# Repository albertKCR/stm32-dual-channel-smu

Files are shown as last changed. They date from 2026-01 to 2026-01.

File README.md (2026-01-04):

# Low-Cost Dual-Channel SMU

An open-source dual-channel Source Measure Unit (SMU) prototype designed for electrical and electrochemical measurements, developed as a Bachelor's thesis in Electronic Engineering.

The system integrates precision analog hardware, embedded firmware, and graphical user interfaces to provide functionality comparable to commercial SMUs at a significantly lower cost.

## Project Overview

This SMU features two fully independent channels, each capable of operating as a potentiostat or galvanostat, supporting common voltammetric and galvanostatic techniques.  
System control is handled by an STM32 microcontroller, with both embedded (DWIN display) and PC-based (C# / WPF) user interfaces.

> **Project status:** Prototype / Research
> 
> **Project total cost:** USD 410.

---

## Repository Structure

This repository is organized as follows:

```text
.
├── DWIN_display_interface     # Embedded graphical interface (DWIN DGUS project)
├── PCB_Gerber                 # PCB fabrication files used for manufacturing and BOM
├── STM32_firmware             # Embedded firmware running on the STM32 microcontroller
├── Schematics                 # Complete electrical schematics of the SMU
├── Windows_interface          # PC-based user interface (C# / WPF)
├── figures                    # Images used in the README and documentation
├── LICENSE                    # Project license
├── bachelor_thesis_pt-br.pdf  # Bachelor's thesis describing the SMU design and validation (pt-br only)
└── README.md

```

---

## System Architecture

### Functional Block Diagram

<!-- INSERT IMAGE: Overall SMU block diagram -->
<!-- Suggested: block diagram showing Power Supply, Voltage Source, Current Source, Ammeter, Voltmeter, MCU, Interfaces -->
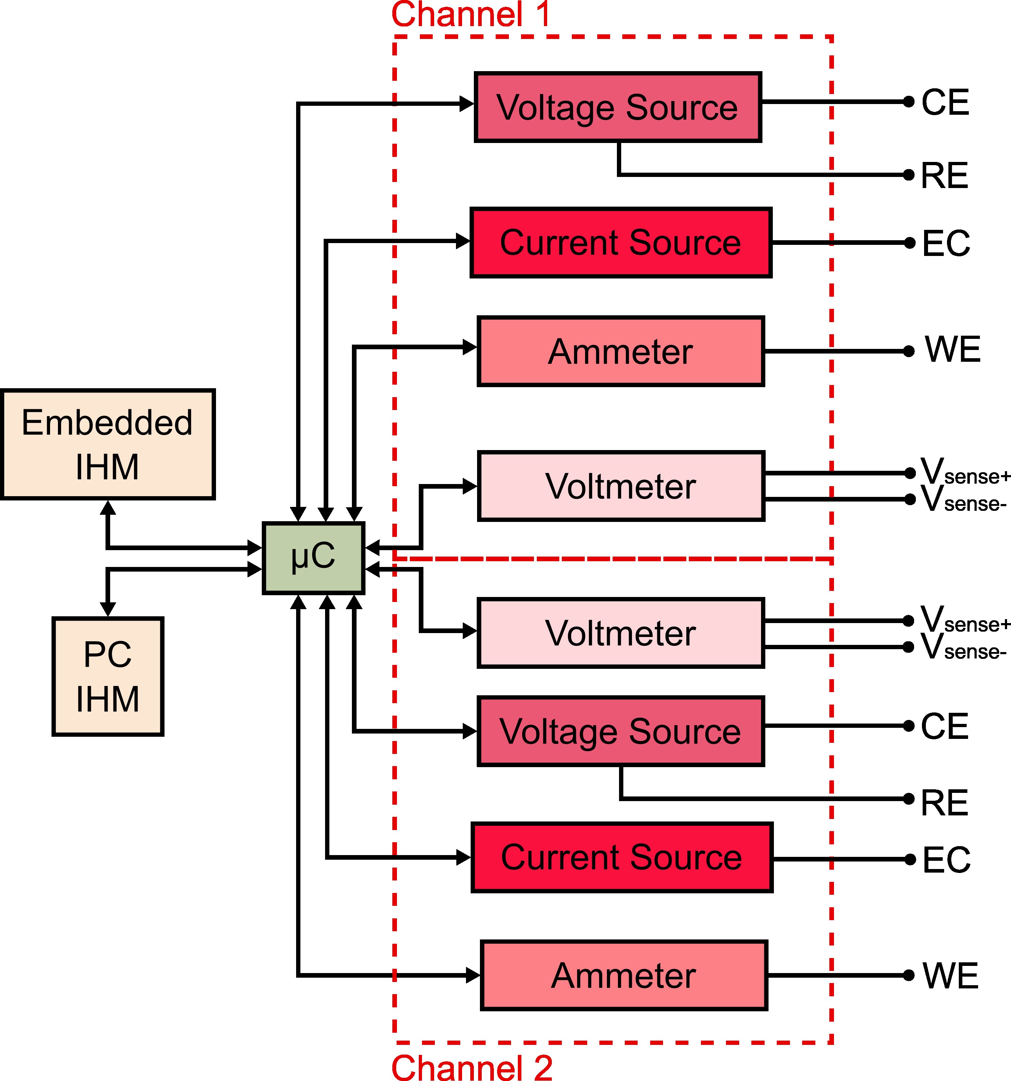
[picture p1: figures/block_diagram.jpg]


The hardware architecture is divided into five main stages per channel:
- Power supply
- Voltage source
- Current source
- Ammeter
- Voltmeter

### Electrodes

### Potentiostat Mode

In potentiostatic operation, the SMU uses a three-electrode configuration:

- Working Electrode (WE): terminal where the electrochemical reaction occurs. The SMU controls its potential relative to the Reference Electrode and measures the resulting current.
- Counter Electrode (CE): provides the current path required to maintain the controlled potential at the Working Electrode.
- Reference Electrode (RE): used exclusively for voltage sensing, providing a stable reference potential without conducting significant current.

For non-electrochemical measurements, the Counter and Reference electrodes may be connected together, allowing the potentiostat to operate as a voltage buffer.

### Galvanostat Mode

In galvanostatic operation, the SMU applies a controlled current and measures the resulting voltage:

- Current Electrode (EC): injects the defined current into the device or electrochemical cell.
- Voltage Sense (+ / −): measure the voltage response independently of the current path, enabling accurate voltage measurements across the device under test.

---

## Hardware Overview

### Key Components

- **DAC8760** – Precision 16-bit DAC for voltage and current generation  
- **ADS1262** – 32-bit ADC for high-resolution voltage and current measurements  
- **ADG1408** – Analog multiplexer for automatic transimpedance gain selection  
- **STM32F401CCU6** – Central controller and communication hub  
- **DWIN DMG80480C070_04WTC** – Embedded HMI display

### Measurement Capabilities

- Output voltage: **−10 V to +10 V**
- Output current: **−10 mA to +10 mA**
- Voltage resolution: ~**500 µV**
- Current resolution: ~**500 pA**
- Automatic current range switching

### PCB

<!-- INSERT IMAGE: PCB top and bottom views -->
<!-- Suggested: rendered PCB + real board photo -->

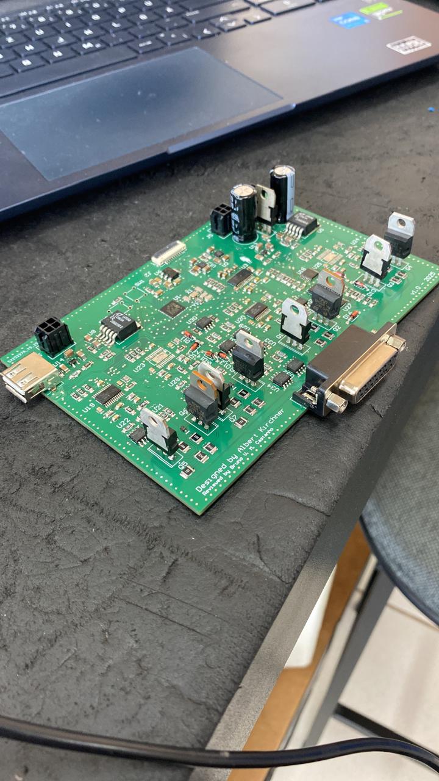
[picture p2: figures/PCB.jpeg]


The PCB integrates all analog, digital, and power stages, including dedicated connectors for electrodes, power input, USB communication, and the DWIN display.

---

## Firmware Architecture

The firmware is written in C using STM32 HAL and organized into modular libraries:

- **DAC8760** – SPI communication and output control
- **ADS1262** – ADC configuration and data acquisition
- **DWIN** – UART-based display communication
- **SMU** – High-level control, measurement logic, and technique execution

The SMU library acts as the core abstraction layer, managing:
- Channel configuration
- Source and measure operations
- Electrochemical techniques
- Communication with both interfaces

---

## Supported Techniques

### Potentiostatic
- Linear Sweep Voltammetry (LSV)
- Cyclic Voltammetry (CV)
- Differential Pulse Voltammetry (DPV)
- Square Wave Voltammetry (SWV)

### Galvanostatic
- Chronopotentiometry (CP)
- Linear Sweep Potentiometry (LSP)
- Cyclic Potentiometry (CyP)

Both **single-channel** and **synchronous dual-channel** measurements are supported.

---

## User Interfaces

### PC Interface (C# / WPF)

<!-- INSERT IMAGE: PC interface screenshot -->
<!-- Suggested: main window showing real-time plots -->
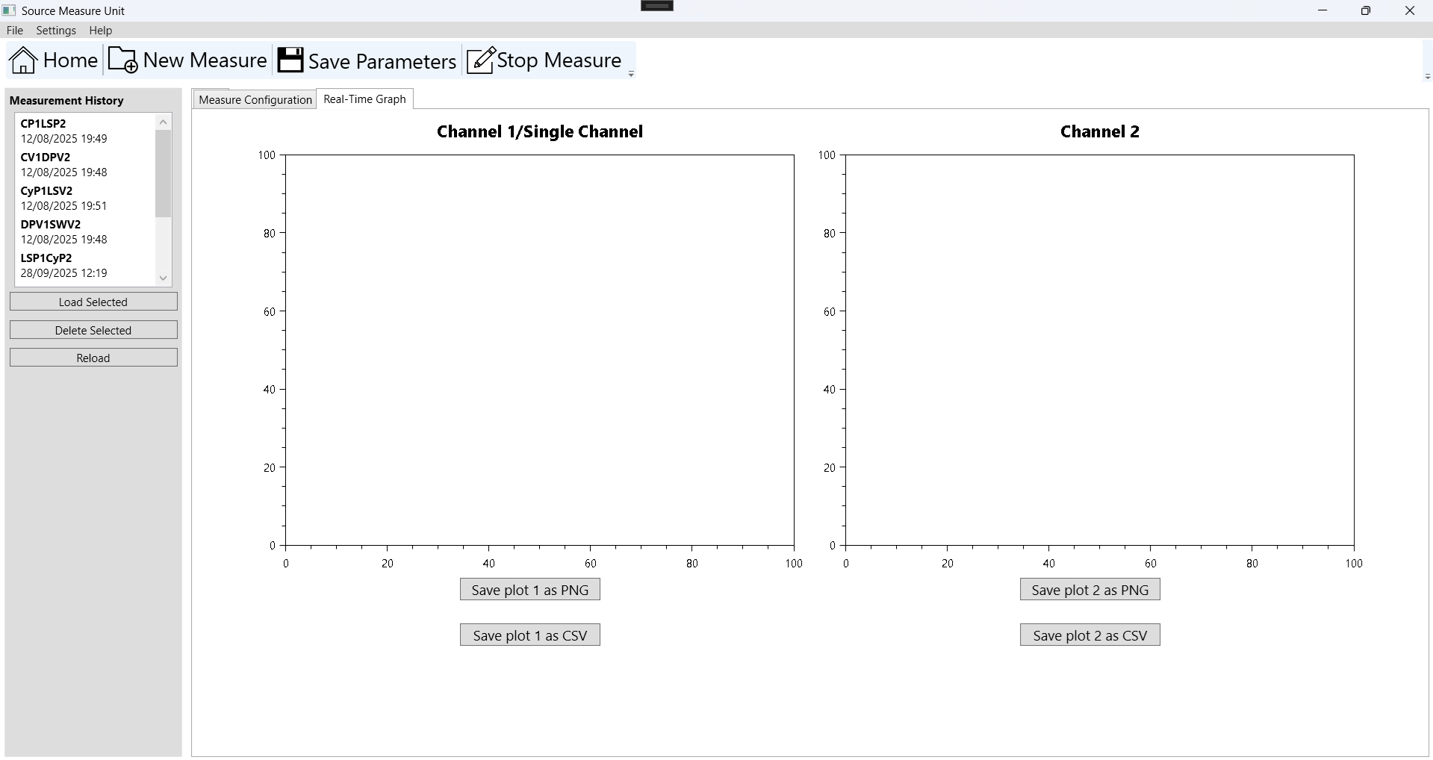
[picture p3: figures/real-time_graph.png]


The PC interface provides:
- Full configuration of measurement parameters
- Real-time plotting
- Dual-channel visualization
- Data export to CSV and PNG
- Measurement history management

Communication is performed via USB-CDC.

### Embedded Interface (DWIN)

<!-- INSERT IMAGE: DWIN display screens -->
<!-- Suggested: menu page + parameter configuration page -->
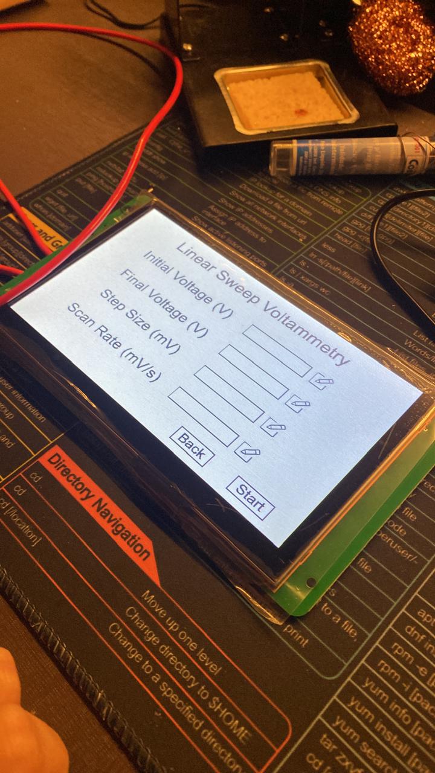
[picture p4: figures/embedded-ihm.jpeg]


The embedded interface enables:
- Standalone operation
- Technique selection
- Parameter configuration
- Numeric display of applied and measured values

---

## Future Work

- Automatic ADS1262 PGA gain selection
- Improved averaging and filtering strategies
- PCB layout refinements
- Higher power output stages

---

## Author

Developed by Albert Kirchner

Bachelor Thesis – Electronics Engineering

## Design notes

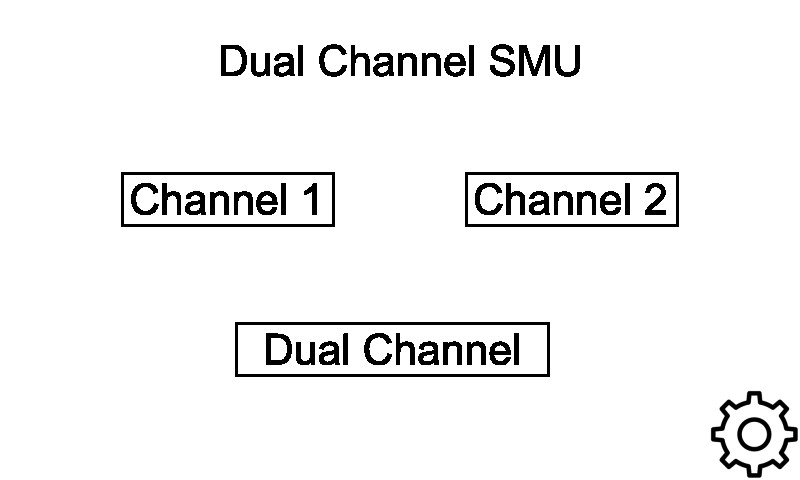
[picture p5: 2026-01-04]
DWIN_display_interface/DWIN_SET/00_dwin_firstPage.jpg

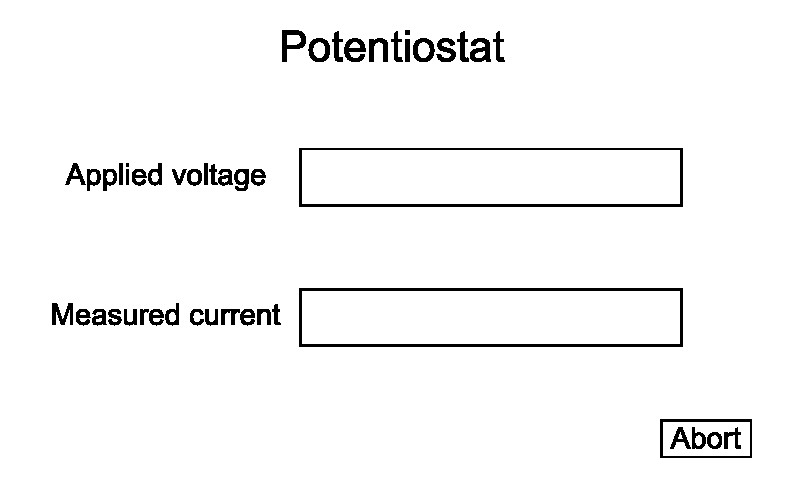
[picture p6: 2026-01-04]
DWIN_display_interface/DWIN_SET/11_dwin_potentiostatReasult.jpg

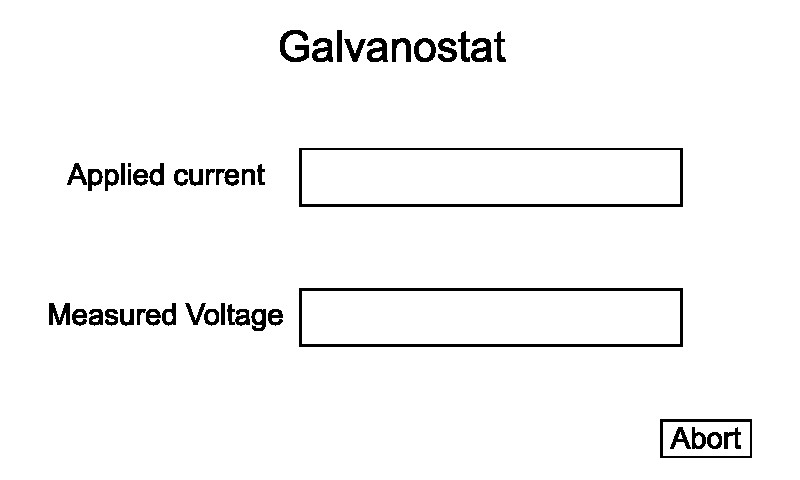
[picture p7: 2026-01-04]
DWIN_display_interface/DWIN_SET/10_dwin_galvanostatReasult.jpg

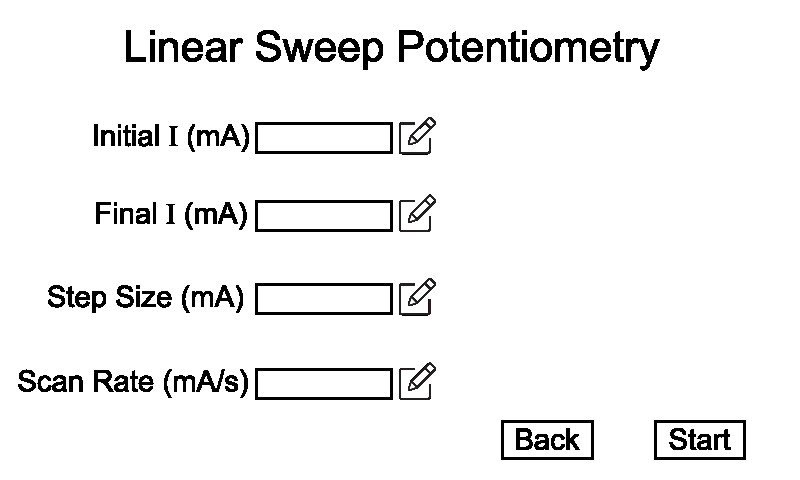
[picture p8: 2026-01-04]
DWIN_display_interface/DWIN_SET/07_dwin_LSP.jpg

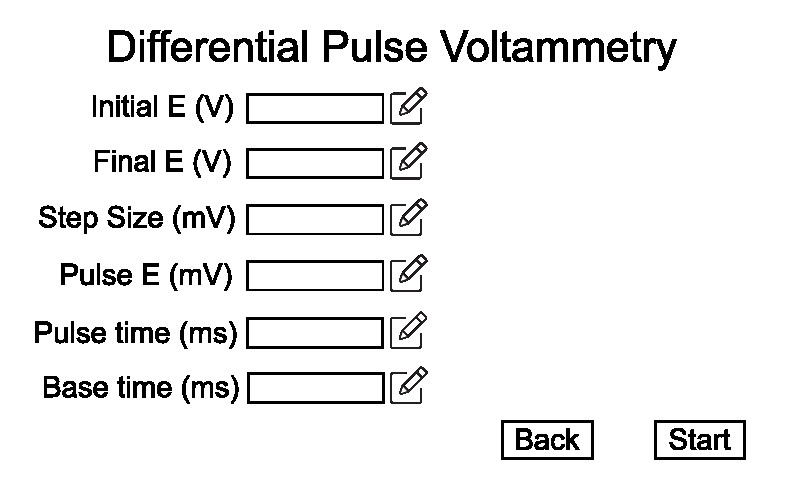
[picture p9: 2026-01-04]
DWIN_display_interface/DWIN_SET/04_dwin_DPV.jpg

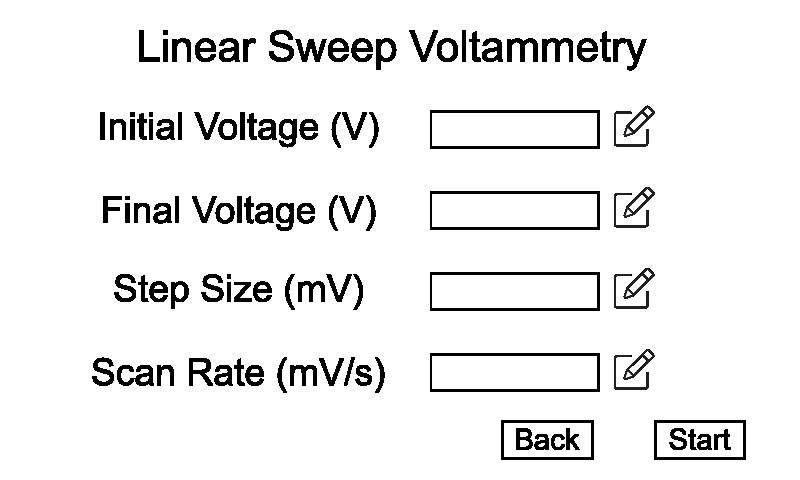
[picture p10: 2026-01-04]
DWIN_display_interface/DWIN_SET/02_dwin_LSV.jpg

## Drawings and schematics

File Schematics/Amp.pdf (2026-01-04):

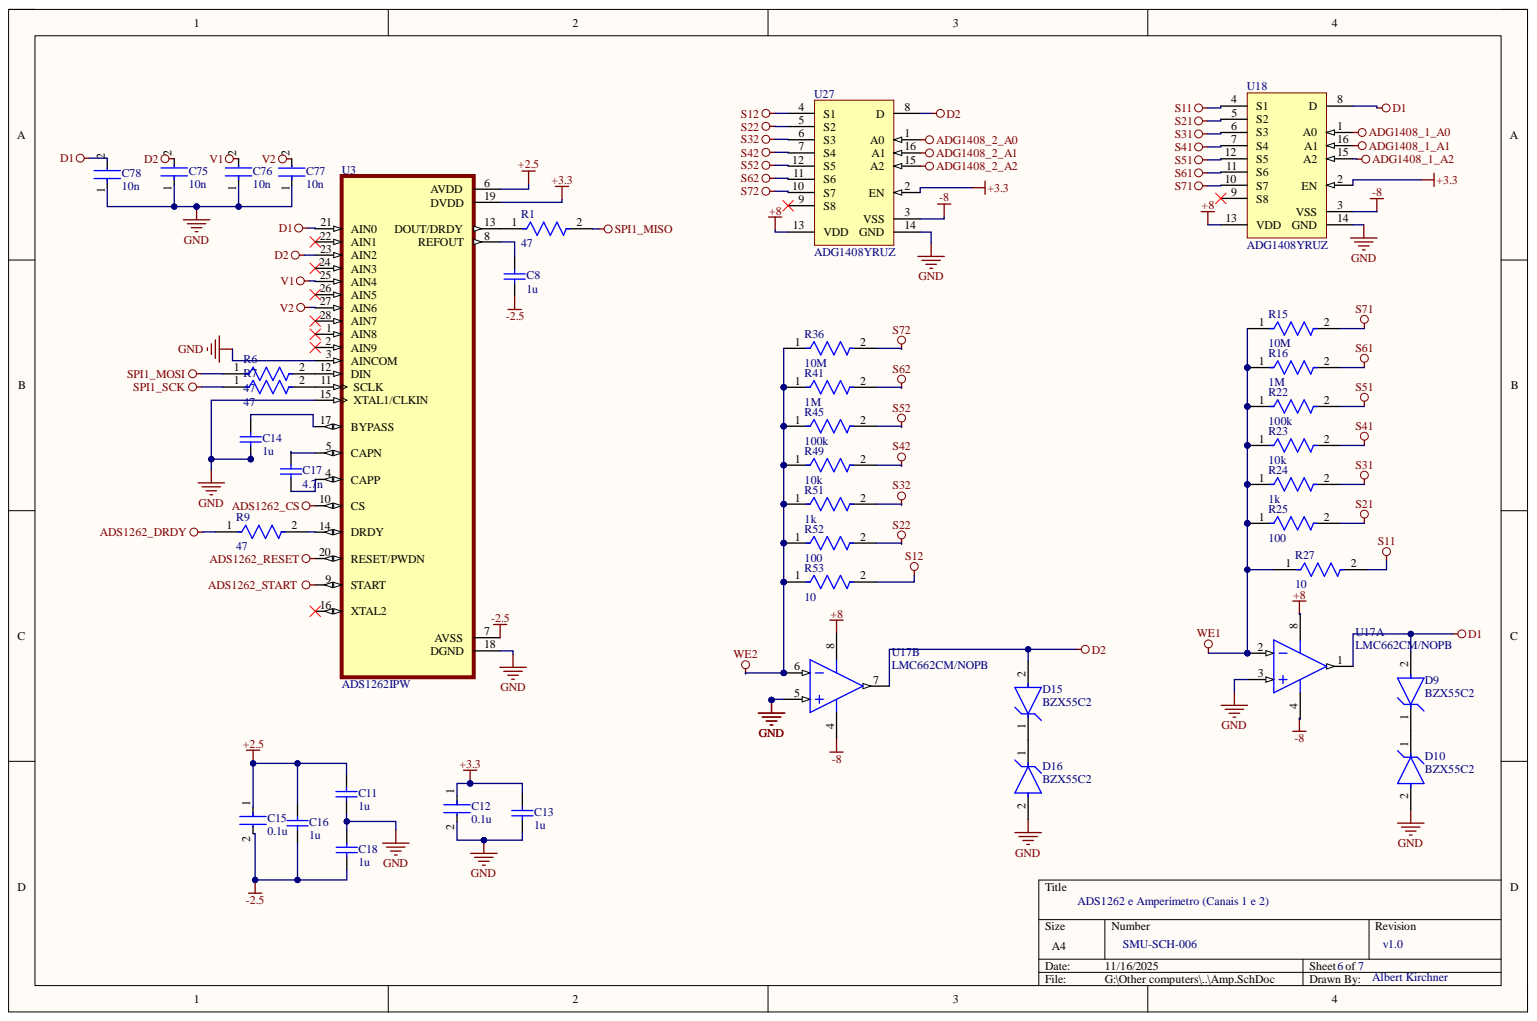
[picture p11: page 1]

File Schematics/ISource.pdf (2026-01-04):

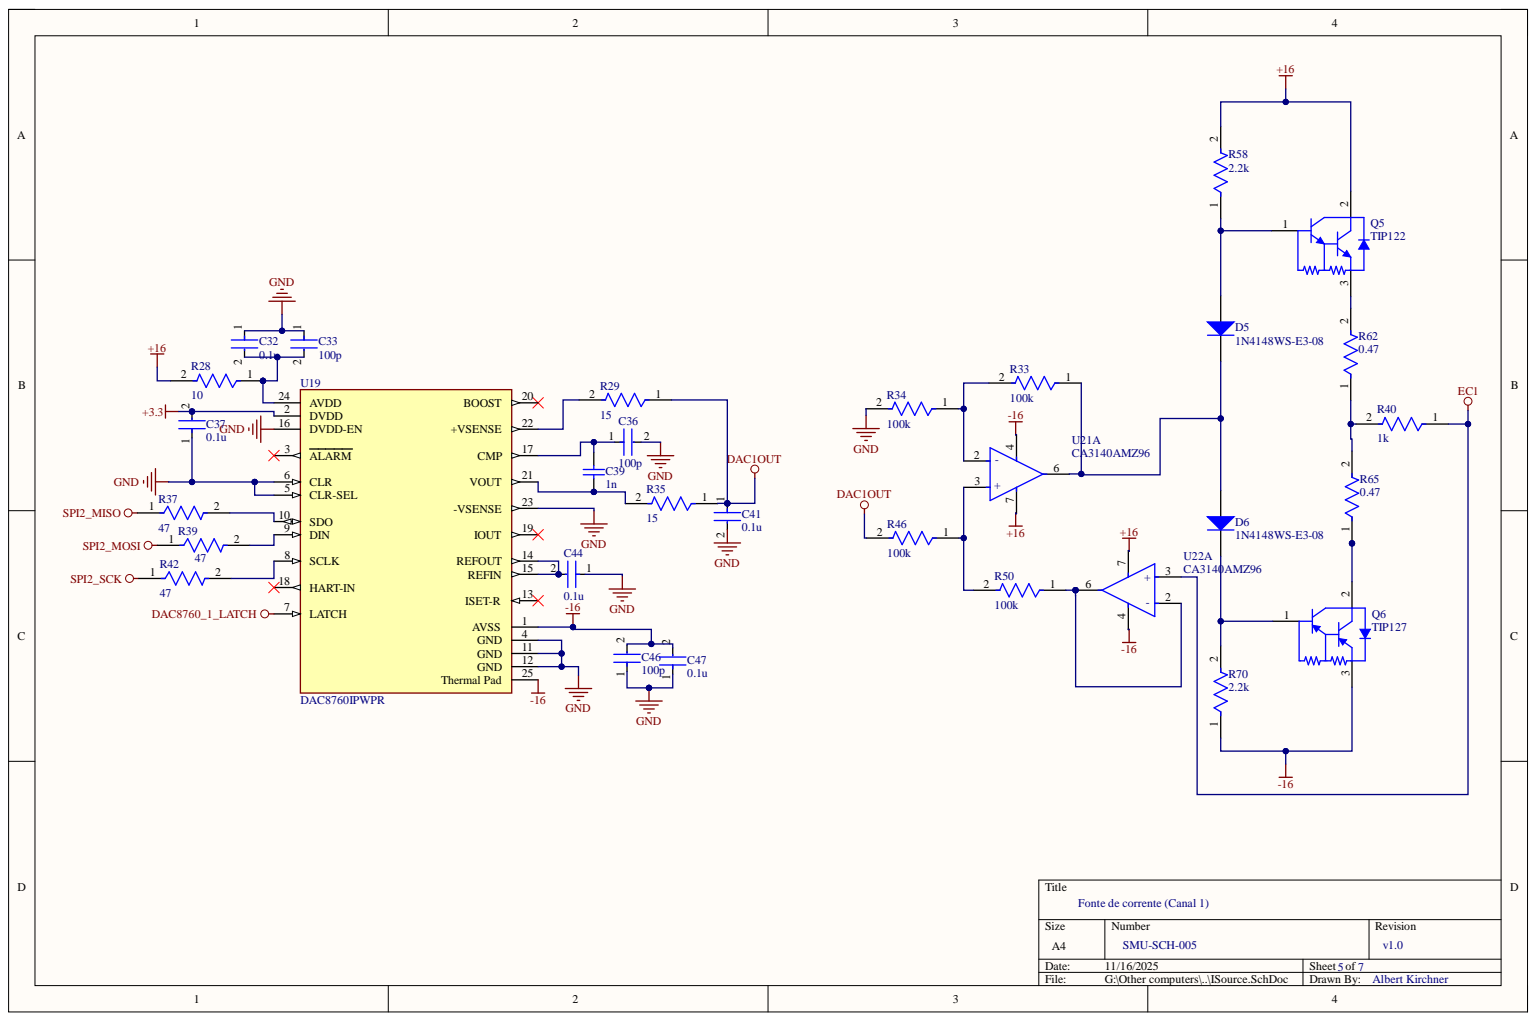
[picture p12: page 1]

1 1
1 2
2 5

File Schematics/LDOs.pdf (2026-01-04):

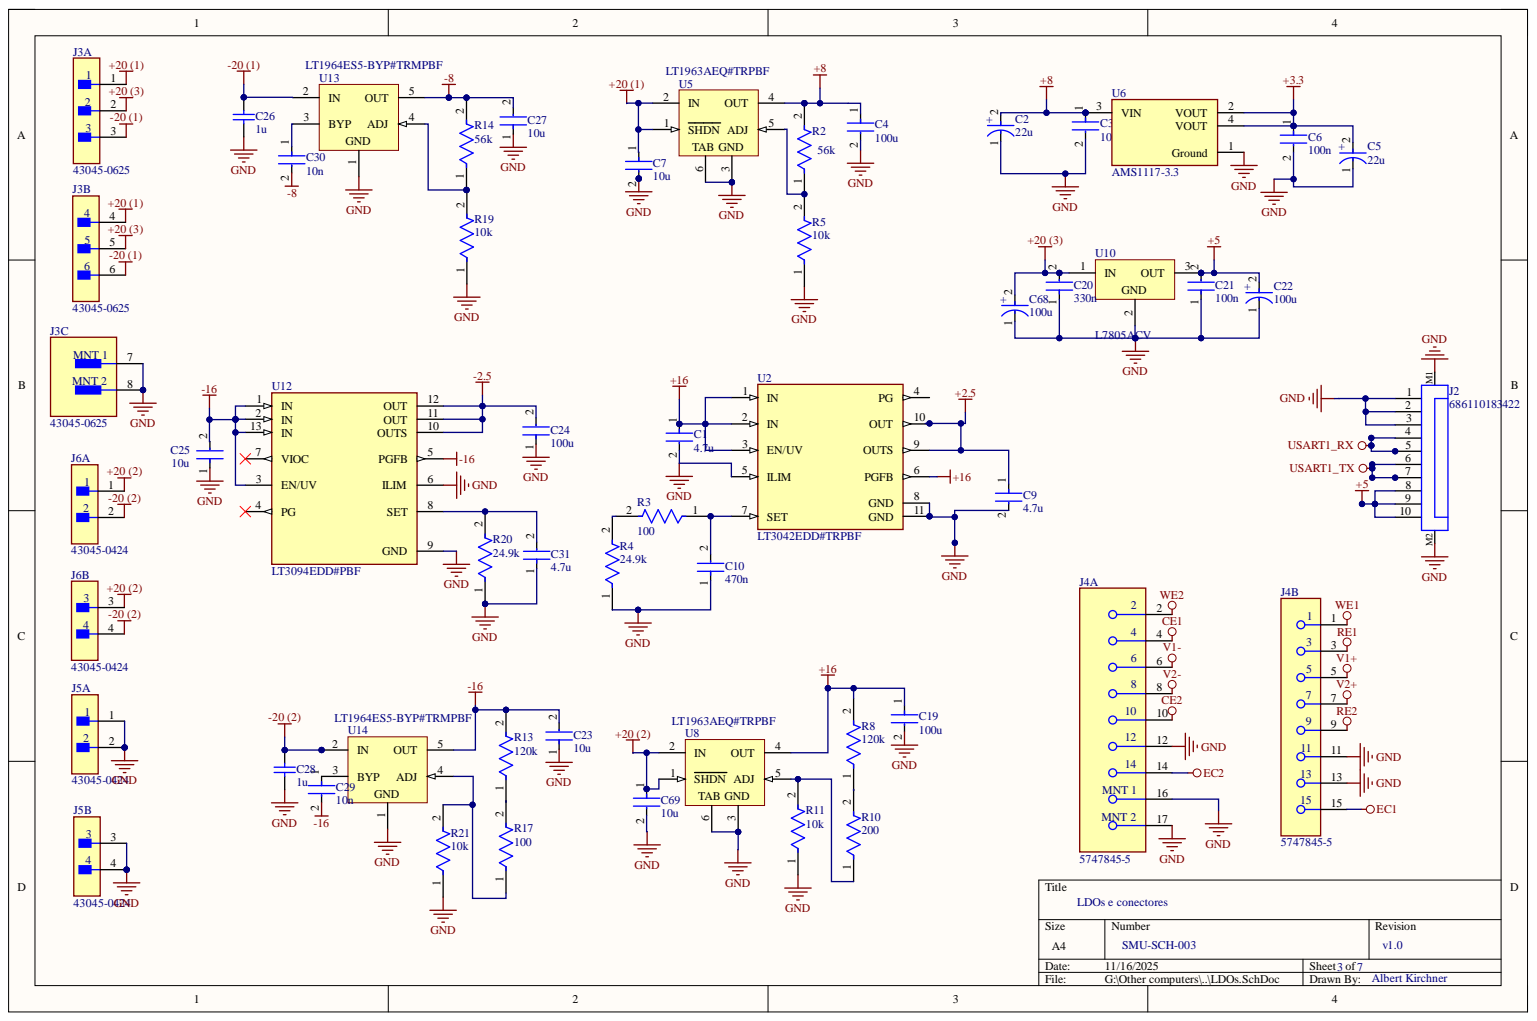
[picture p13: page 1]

2 | | 1 1
1 3 | | 1 0

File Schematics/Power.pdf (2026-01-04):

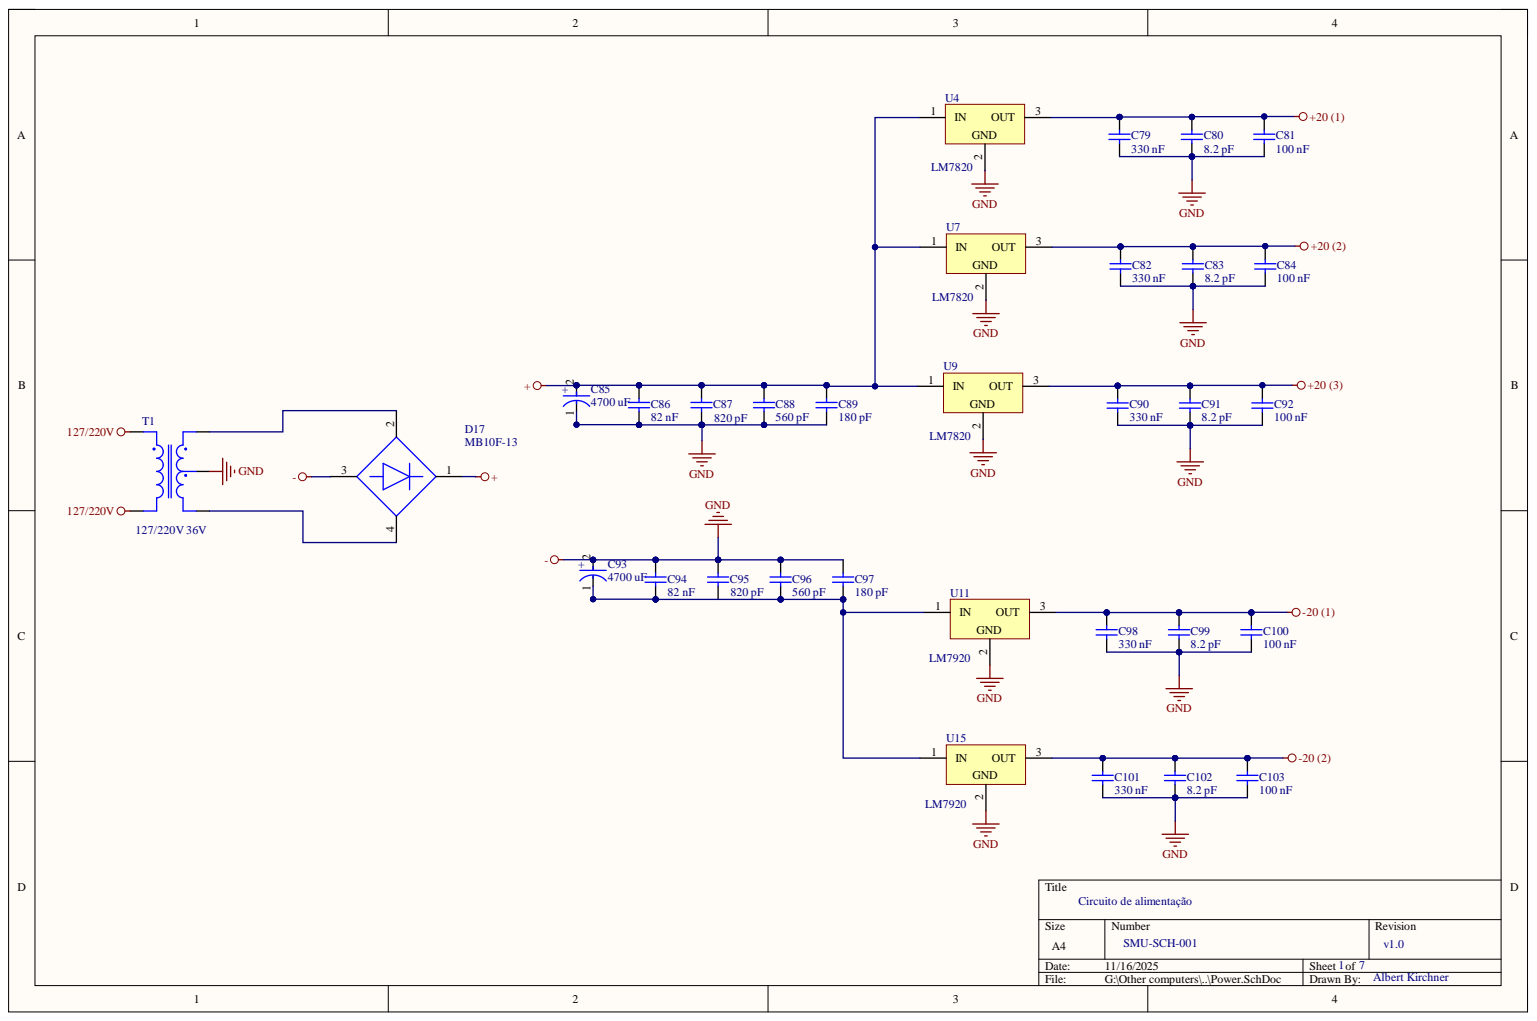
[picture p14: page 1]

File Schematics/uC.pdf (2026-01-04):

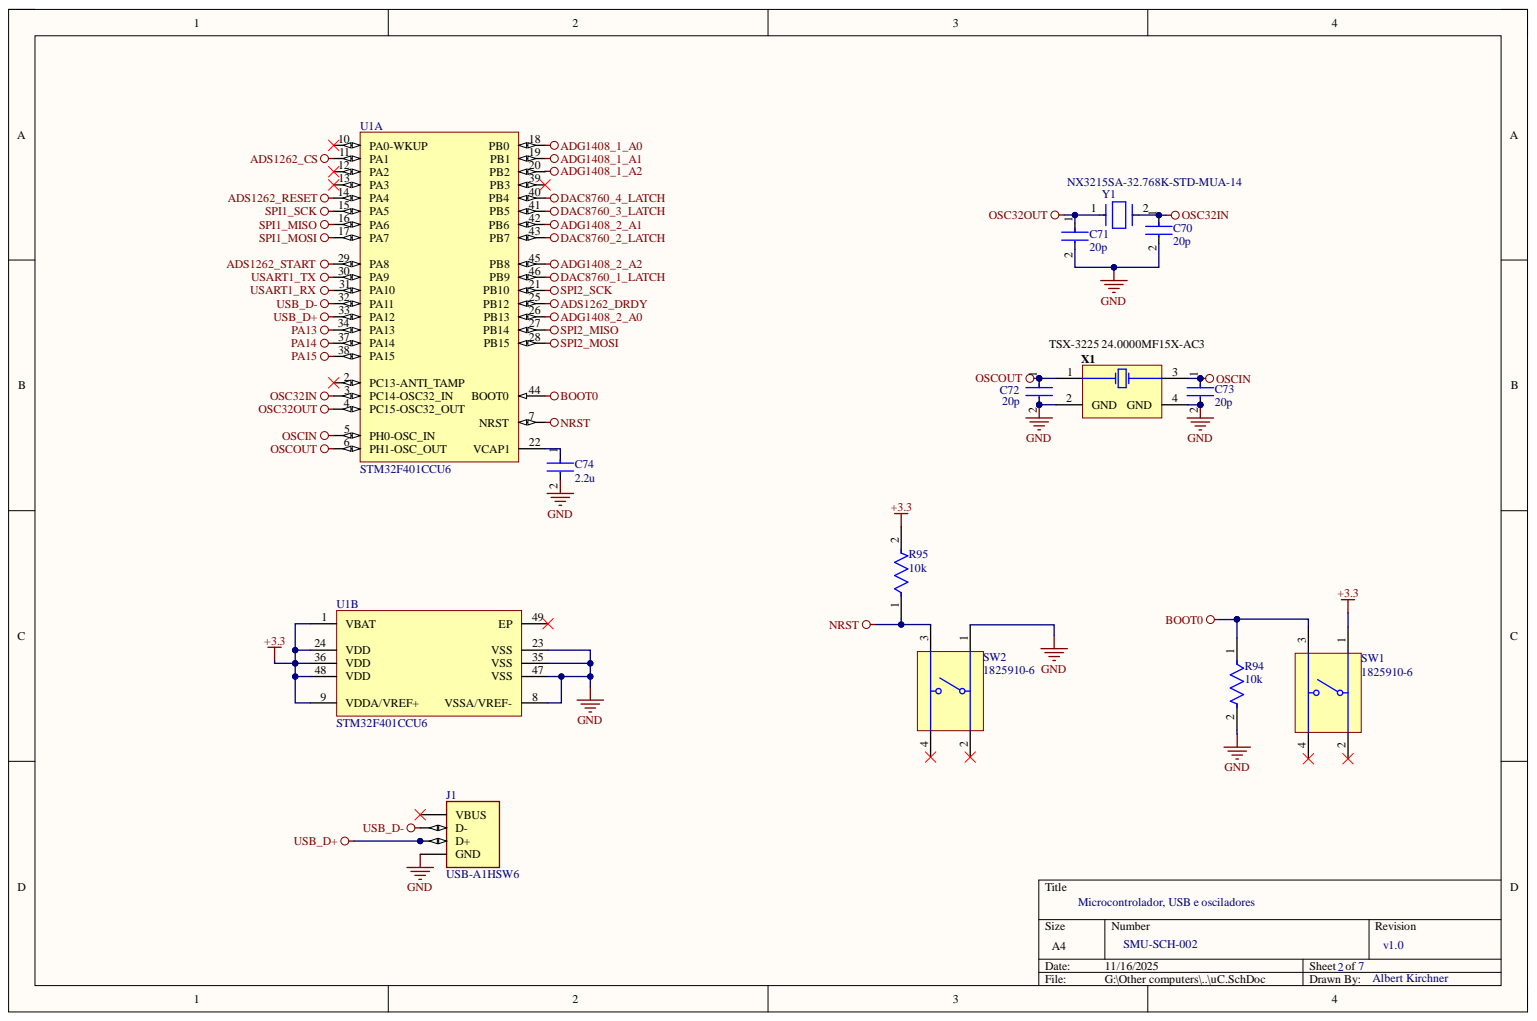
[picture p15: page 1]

2 4 | 2 3
3 6 | 3 5
4 8 | 4 7

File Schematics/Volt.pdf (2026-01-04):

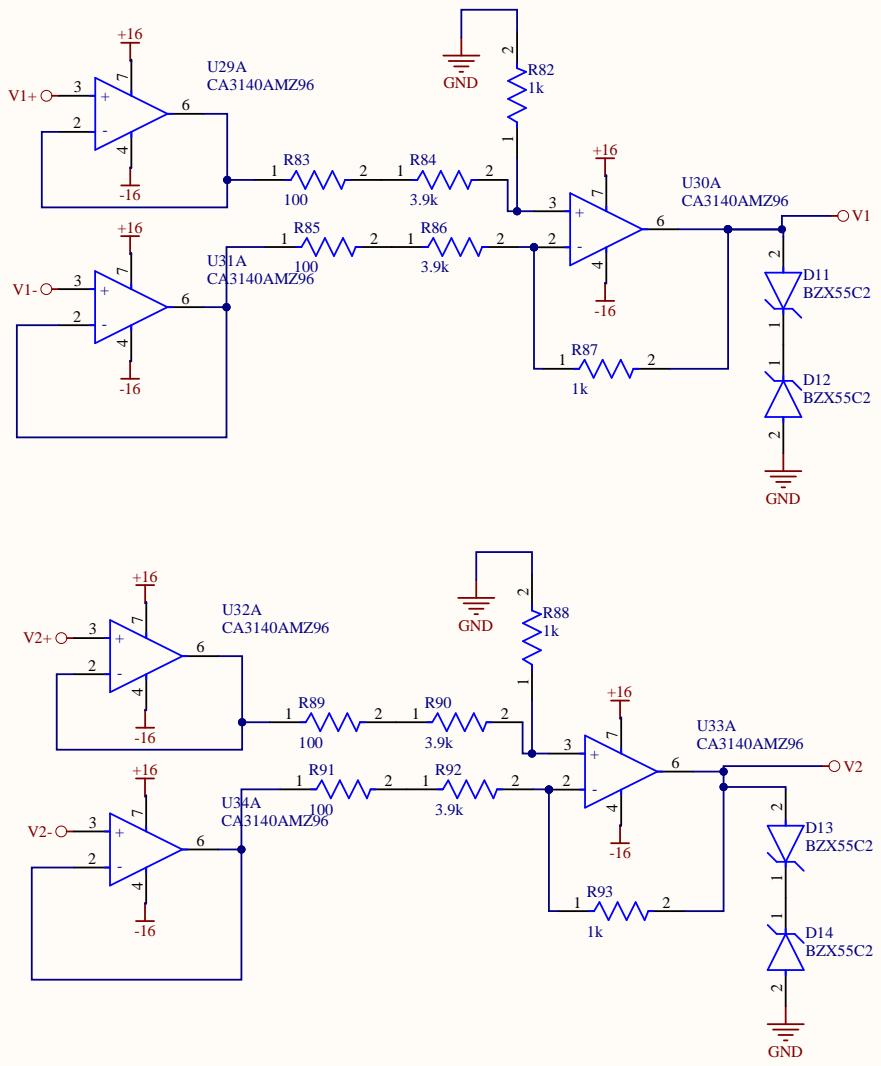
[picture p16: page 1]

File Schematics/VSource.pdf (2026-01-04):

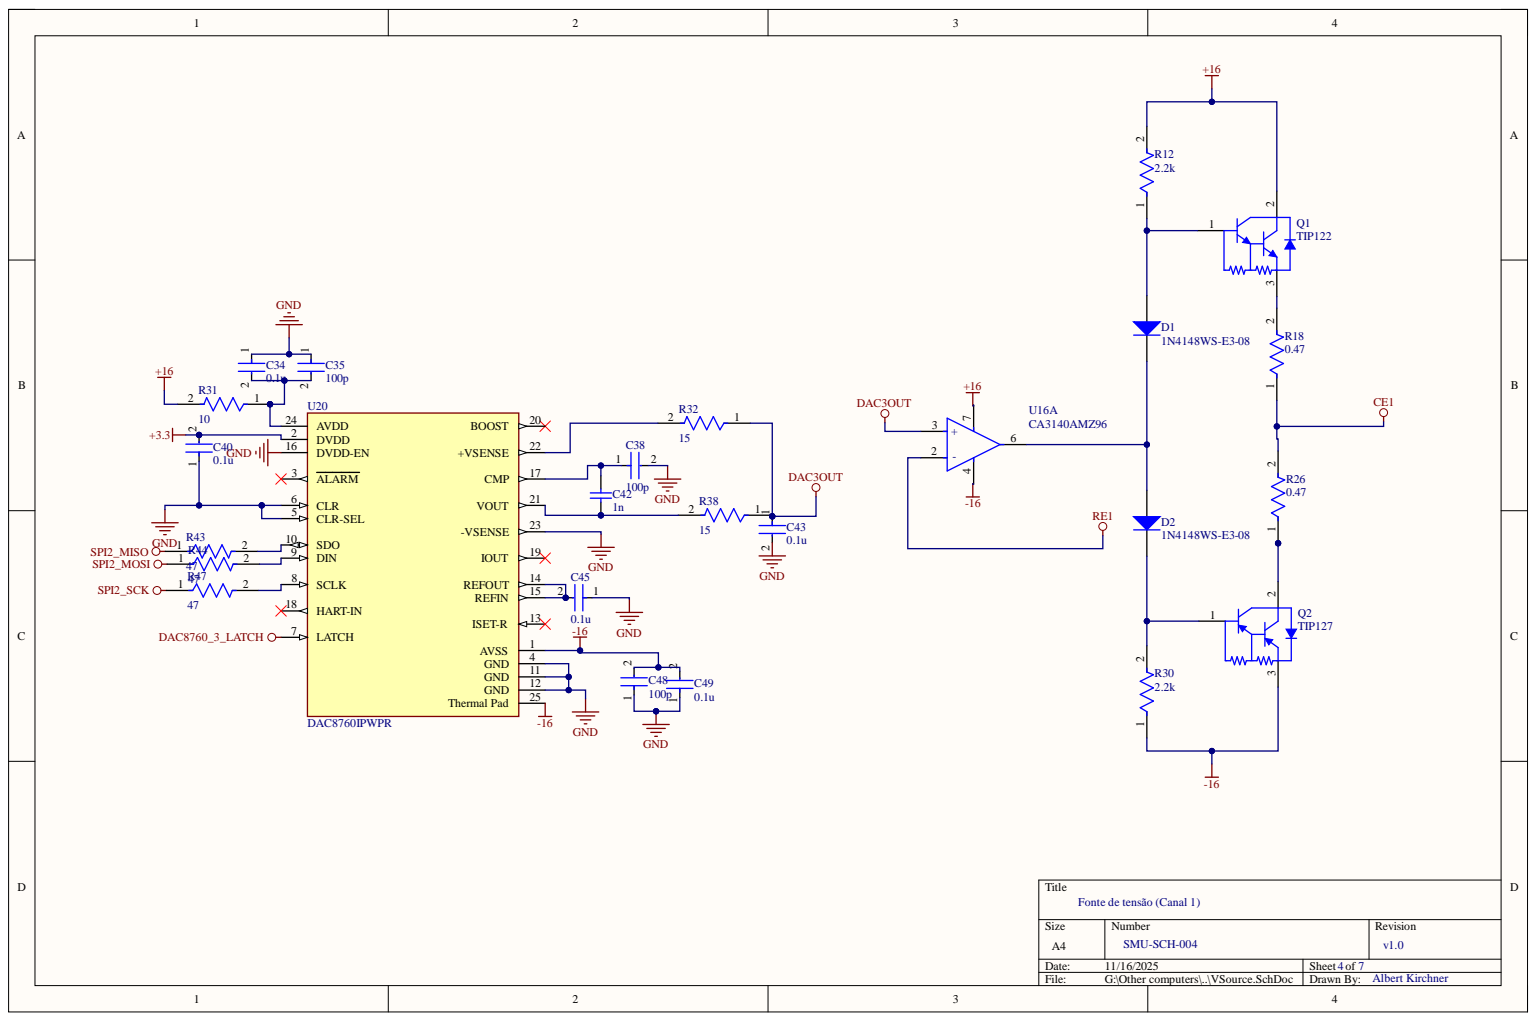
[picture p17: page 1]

1 1
1 2
2 5

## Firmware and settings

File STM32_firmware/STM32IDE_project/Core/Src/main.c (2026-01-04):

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
/* Includes ------------------------------------------------------------------*/
#include "main.h"
#include "usb_device.h"

/* USER CODE BEGIN Includes */
#include "SMU.h"
#include "ADS1262.h"
#include "DAC8760.h"
#include "DWIN.h"
/* USER CODE END Includes */

SPI_HandleTypeDef hspi1;
SPI_HandleTypeDef hspi2;

TIM_HandleTypeDef htim2;

UART_HandleTypeDef huart1;

/* USER CODE BEGIN PV */
channel_t Channel1;
channel_t Channel2;
DAC8760_t Ch1_Potentiostat_DAC; // Potentiostat Channel 1
DAC8760_t Ch1_Galvanostat_DAC;  // Galvanostat Channel 1
DAC8760_t Ch2_Potentiostat_DAC; // Potentiostat Channel 2
DAC8760_t Ch2_Galvanostat_DAC;  // Galvanostat Channel 2

char input[64];
uint8_t USB_newData;

int currentAmmeterResistorIndex = 2;
float currentAmmeterResistor = 1000;
float ammeterResistors [7] = {10, 100, 1000, 10000, 100000, 1000000, 10000000};
float currentSourceResistor = 1000;
int pageID;
uint8_t dwinChannel;
bool HMIflag;   // HMI flag -> 0 PC ; 1 DWIN display


/* USER CODE END PV */

void SystemClock_Config(void);
static void MX_GPIO_Init(void);
static void MX_SPI1_Init(void);
static void MX_SPI2_Init(void);
static void MX_USART1_UART_Init(void);
static void MX_TIM2_Init(void);
/**
  * @brief  The application entry point.
  * @retval int
  */
int main(void)
{

  /* MCU Configuration--------------------------------------------------------*/

  /* Reset of all peripherals, Initializes the Flash interface and the Systick. */
  HAL_Init();

  /* Configure the system clock */
  SystemClock_Config();

  /* Initialize all configured peripherals */
  MX_GPIO_Init();
  MX_SPI1_Init();
  MX_SPI2_Init();
  MX_USART1_UART_Init();
  MX_USB_DEVICE_Init();
  MX_TIM2_Init();
  HAL_TIM_Base_Start(&htim2);
  /* USER CODE BEGIN 2 */
  SMU_Init(hspi2);
  char charData[15];

  int32_t adc_data = 0;
  double voltage = 0;
  double current = 0;

  HAL_GPIO_WritePin(ADG1408_1_A0_GPIO_Port, ADG1408_1_A0_Pin, GPIO_PIN_RESET);
  HAL_GPIO_WritePin(ADG1408_1_A1_GPIO_Port, ADG1408_1_A1_Pin, GPIO_PIN_SET);
  HAL_GPIO_WritePin(ADG1408_1_A2_GPIO_Port, ADG1408_1_A2_Pin, GPIO_PIN_RESET);

  HAL_GPIO_WritePin(ADG1408_2_A0_GPIO_Port, ADG1408_2_A0_Pin, GPIO_PIN_RESET);
  HAL_GPIO_WritePin(ADG1408_2_A1_GPIO_Port, ADG1408_2_A1_Pin, GPIO_PIN_RESET);
  HAL_GPIO_WritePin(ADG1408_2_A2_GPIO_Port, ADG1408_2_A2_Pin, GPIO_PIN_RESET);

  //currentAmmeterResistor = 1000;

  SMU_SetCurrent(0, Channel1); // galvanostat*
  SMU_SetVoltage(0, Channel2);
  /* USER CODE END 2 */

  /* Infinite loop */
  /* USER CODE BEGIN WHILE */
  while (1)
  {
	  if (USB_newData == 1)
	  {
		  pc_interface();
		  USB_newData=0;
	  }
	  //waitForDwin();

	  /*(ADS1262_setAIN(AIN0, AINCOM);
	  adc_data = ADS1262_ReadData();

	  voltage = (double)adc_data * (2.5 / pow(2, 31));

	  sprintf(charData, "%f \n", voltage);
	  //sprintf(charData, "%X \n", (uint8_t)((AIN6 << 4) | AINCOM));
	  CDC_Transmit_FS((uint8_t *) charData, strlen(charData));*/

	  /*SMU_SetCurrent(0.001, Channel1); // galvanostat*
	  SMU_SetVoltage(1, Channel2);*/

    /* USER CODE END WHILE */

    /* USER CODE BEGIN 3 */
  }
  /* USER CODE END 3 */
}

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


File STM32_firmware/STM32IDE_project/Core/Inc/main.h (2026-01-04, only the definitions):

#define ADS1262_CS_Pin GPIO_PIN_1
#define ADS1262_CS_GPIO_Port GPIOA
#define ADS1262_RESET_Pin GPIO_PIN_4
#define ADS1262_RESET_GPIO_Port GPIOA
#define ADG1408_1_A0_Pin GPIO_PIN_0
#define ADG1408_1_A0_GPIO_Port GPIOB
#define ADG1408_1_A1_Pin GPIO_PIN_1
#define ADG1408_1_A1_GPIO_Port GPIOB
#define ADG1408_1_A2_Pin GPIO_PIN_2
#define ADG1408_1_A2_GPIO_Port GPIOB
#define ADS1262_DRDY_Pin GPIO_PIN_12
#define ADS1262_DRDY_GPIO_Port GPIOB
#define ADG1408_2_A0_Pin GPIO_PIN_13
#define ADG1408_2_A0_GPIO_Port GPIOB
#define ADS1262_START_Pin GPIO_PIN_8
#define ADS1262_START_GPIO_Port GPIOA
#define DAC8760_3_LATCH_Pin GPIO_PIN_5
#define DAC8760_3_LATCH_GPIO_Port GPIOB
#define ADG1408_2_A1_Pin GPIO_PIN_6
#define ADG1408_2_A1_GPIO_Port GPIOB
#define DAC8760_2_LATCH_Pin GPIO_PIN_7
#define DAC8760_2_LATCH_GPIO_Port GPIOB
#define ADG1408_2_A2_Pin GPIO_PIN_8
#define ADG1408_2_A2_GPIO_Port GPIOB
#define DAC8760_1_LATCH_Pin GPIO_PIN_9
#define DAC8760_1_LATCH_GPIO_Port GPIOB

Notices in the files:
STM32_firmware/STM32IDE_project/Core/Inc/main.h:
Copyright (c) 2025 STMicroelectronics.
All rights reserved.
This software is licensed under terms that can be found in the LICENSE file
